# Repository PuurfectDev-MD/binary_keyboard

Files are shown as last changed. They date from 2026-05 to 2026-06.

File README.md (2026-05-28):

# Binary Keyboard
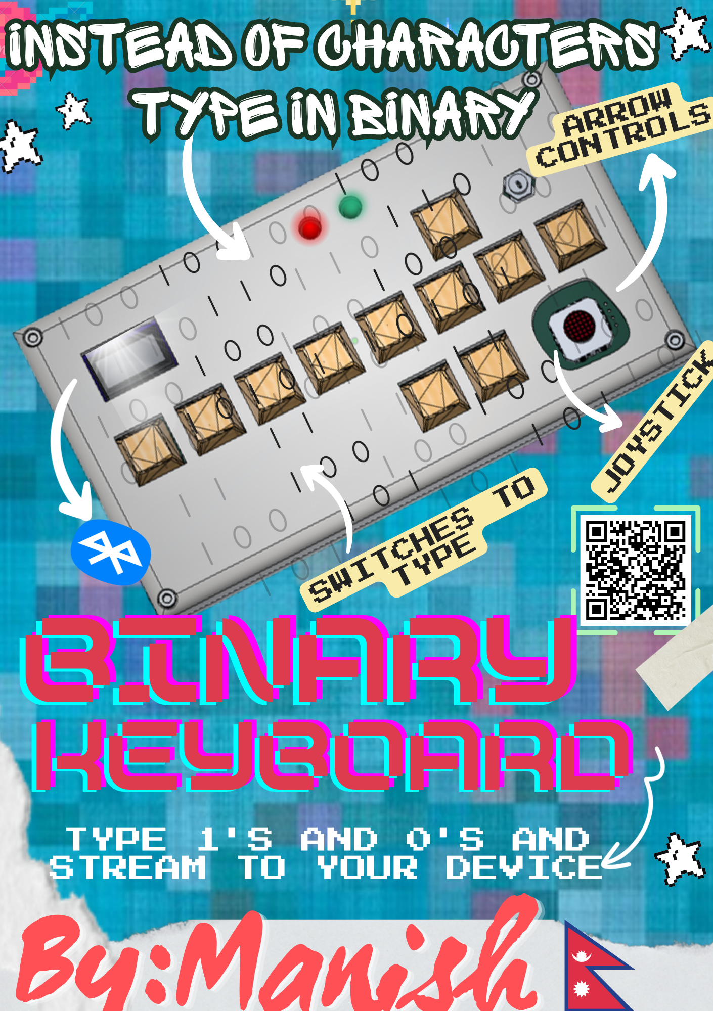
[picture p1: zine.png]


This is wacky, silly project where you can type your keyboard inputs in binary and send it to a connected device. You can enter the byte values (8 switches represent 8 bits in a byte) which represents a character. Then you confirm your input with the enter switch to covert that binary byte to a character to send to your device (wired or wireless!). Basically a keyboard but you type in binary because why not! It uses the SuperMini nRF52840 mcu ( a nice!nano clone) which supports bluetooth connectivity for you to send your inputs wirelessly.

## Motivation
I build the binary keyboard just for the sake of learning. No other motives. Its just a very stupid and fun idea which struck me and there I went building :)

## PCB

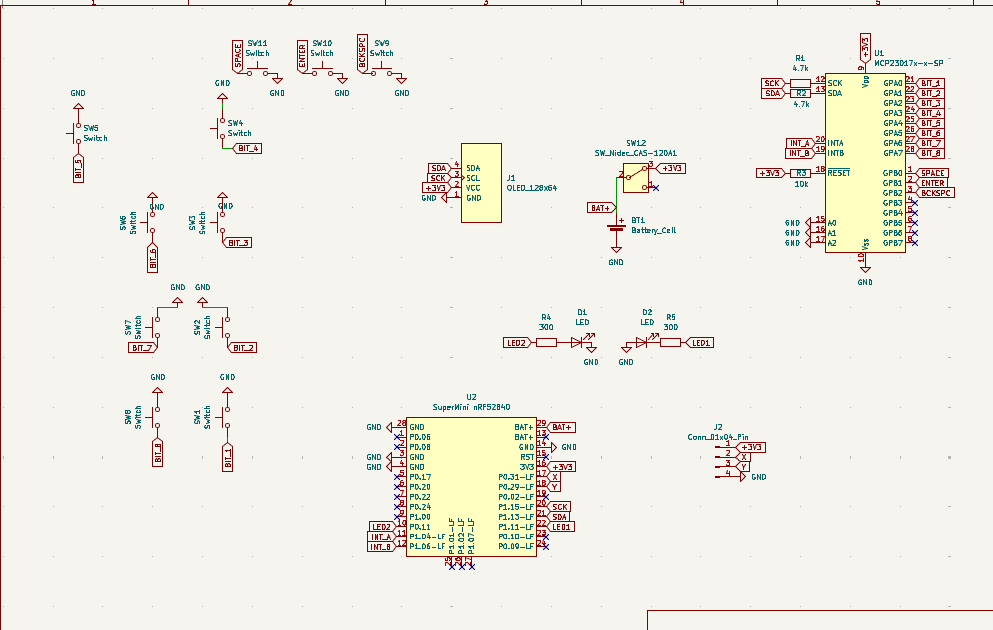
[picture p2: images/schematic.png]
Schematic

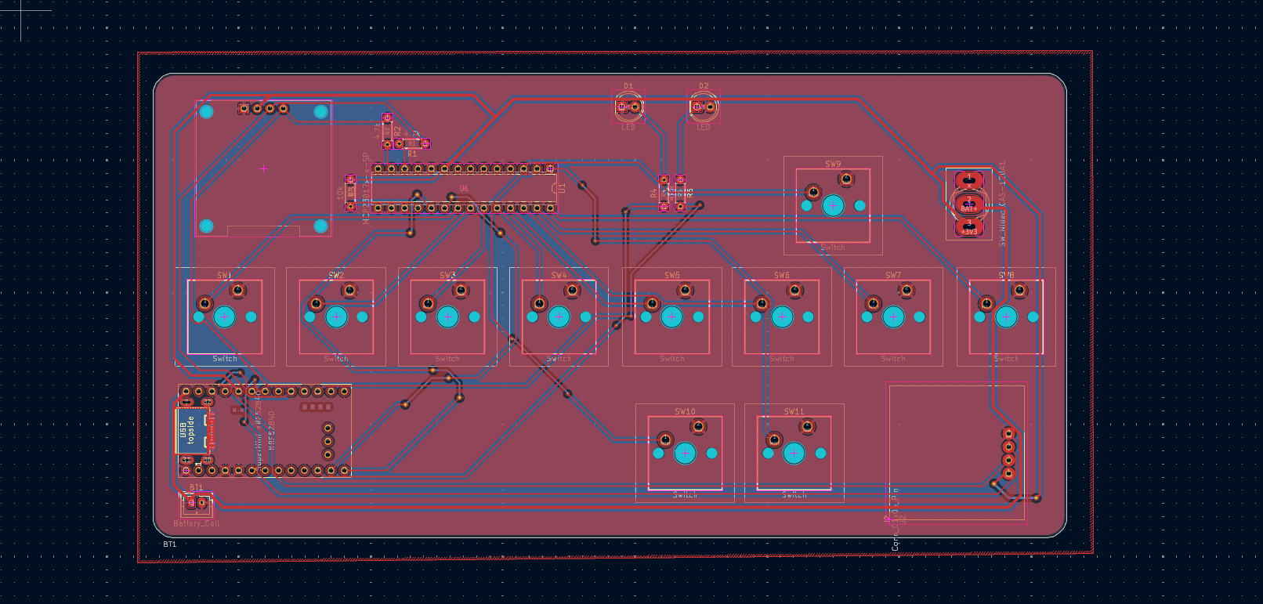
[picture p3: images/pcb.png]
PCB


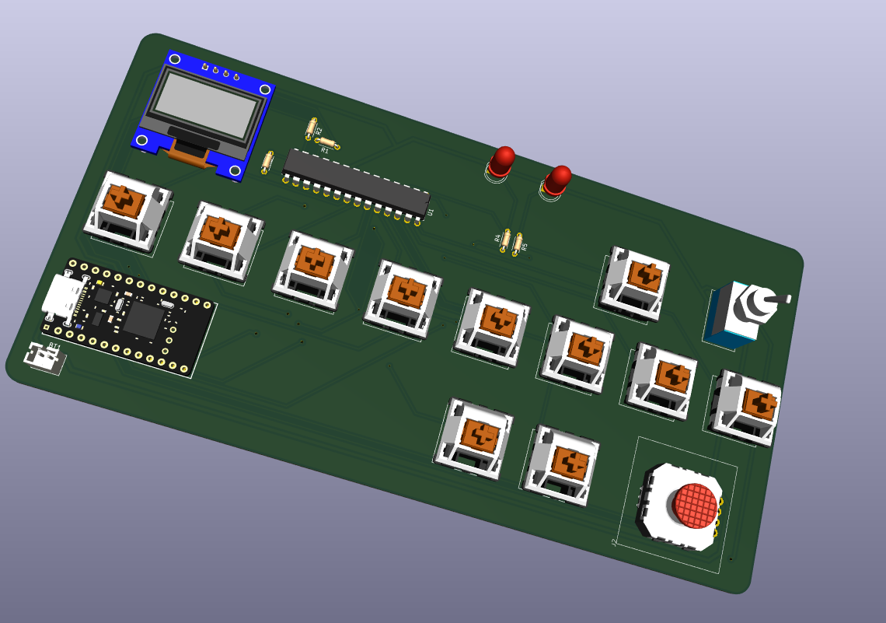
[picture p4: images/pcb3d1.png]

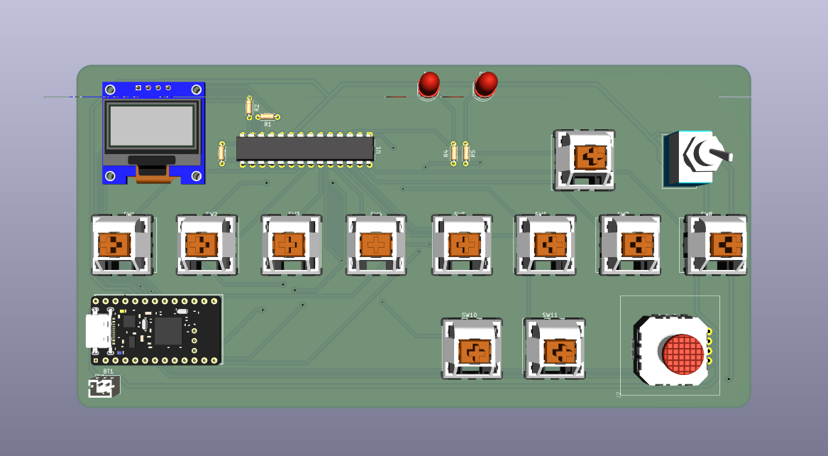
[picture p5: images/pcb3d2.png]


## 3D case
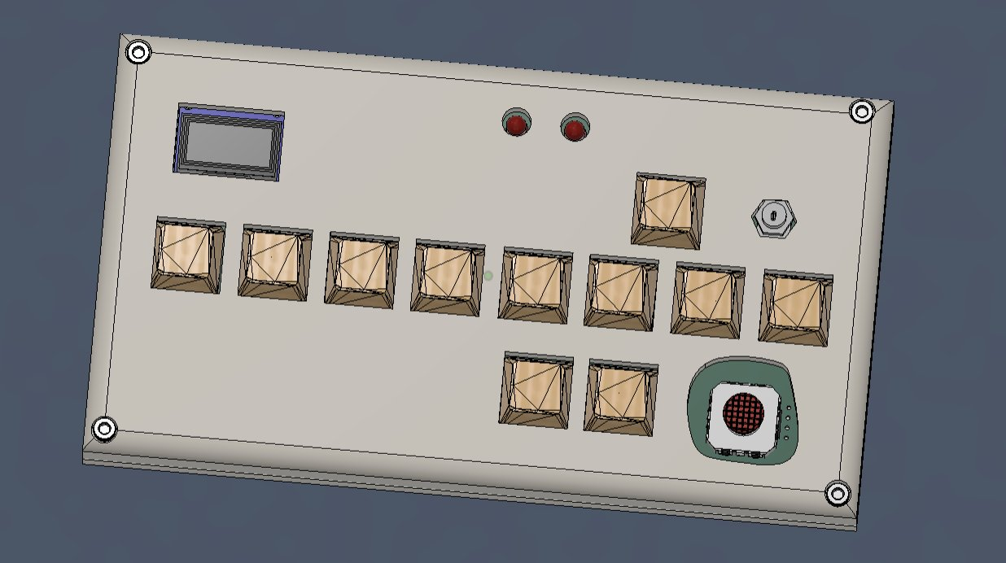
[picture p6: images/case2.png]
Case

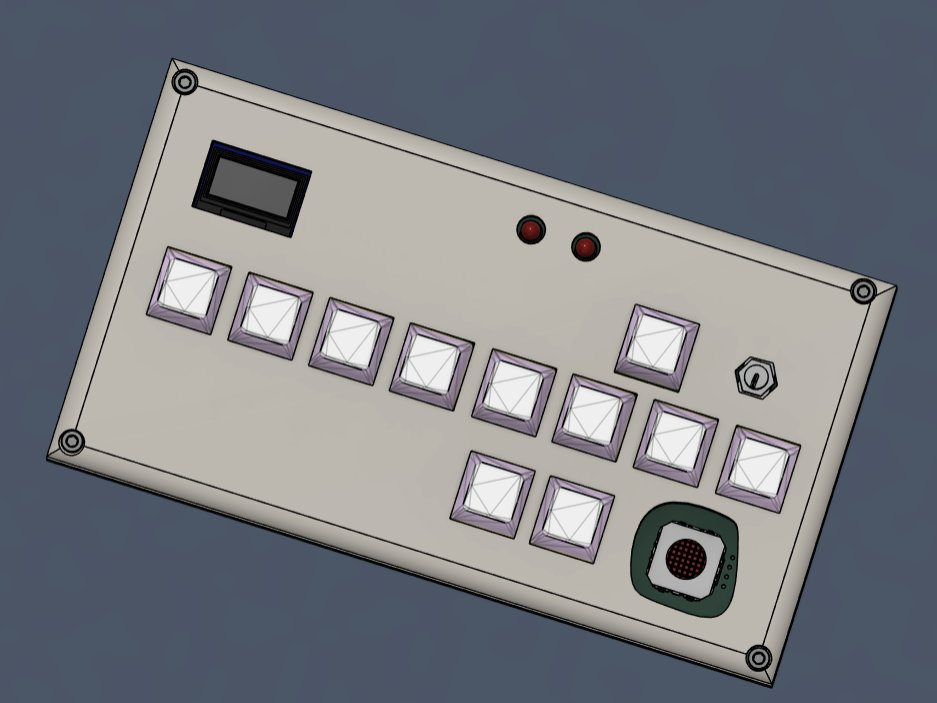
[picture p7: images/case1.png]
Case


##  Project Structure

```text
├── 📁 3d_models
│   ├── 📁 Fusion 360     # Contains the .f3d files and STEP files
│   └── 📁 PCB export     # The 3d file exported from KiCad
├── 📁 KiCad              # Contains the KiCad schematics and PCB files 
├── 📁 Firmware
│   ├── 📁 Circuit Python # Contains the uf2 file that is to be flashed to the supermini
│   ├── 📁 lib            # Contains a zip file for the circuitpython firmware
│   └── 📄 code.py        # Contains the main code
└── 📁 BOM
    ├── 📄 kicad.csv      # KiCad generated CSV (no price present)
    └── 📄 BOM.cBOM mnaully created with price and total estimation
```

## How it works 
There are an array of 8 switches that are connected to the GPA0 to GPA7 of the MCP23017 gpio expander. The GPB0 has three connections - (SPACE, BACKSPACE and ENTER). There are intrerrupts for both of them which are conencted to gpios of the mcu. Whenever a user presses a button (any of the 8 buttons that repsresnt 1 bit of a byte for a single char) the state is changed for that bit's value. So if it was a 0 it changes to 1. Like that we can toggle each of the bits state and at the end press the enter button to confirm the data input. Then the python script (code.py) converted the byte to a char by mapping it to a character and returns it to the USB_HID device for it to be printed on your screen.

## How to make it work for you
First print the PCB. Print the 3d case. Then solder the parts in place. For the firmware- flash the uf2 file in the supermini. Then install the firmware into the mcy by unzippping the file inside /Firmware/lib. And upload the code.py file to begin testing and using the device.    

## AI USE
For firmware guidance and the code.py file code. Teensy help on fusion on selecting screw and other minor stuff. And small help for debugging kicad schematic and suggestions for improvements.

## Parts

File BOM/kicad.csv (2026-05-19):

Reference | Qty | Value | DNP | Exclude from BOM | Exclude from Board | Footprint | Datasheet
BT1 | 1 | Battery_Cell |  |  |  | Connector_JST:JST_PH_B2B-PH-K_1x02_P2.00mm_Vertical
D1,D2 | 2 | LED |  |  |  | LED_THT:LED_D5.0mm
J1 | 1 | OLED_128x64 |  |  |  | ScottoKeebs_Components:OLED_128x64
J2 | 1 | Conn_01x04_Pin |  |  |  | small _yoystick:footprint25.8 * 25.8
R1,R2 | 2 | 4.7k |  |  |  | Resistor_THT:R_Axial_DIN0204_L3.6mm_D1.6mm_P5.08mm_Horizontal
R3 | 1 | 10k |  |  |  | Resistor_THT:R_Axial_DIN0204_L3.6mm_D1.6mm_P5.08mm_Horizontal
R4,R5 | 2 | 300 |  |  |  | Resistor_THT:R_Axial_DIN0204_L3.6mm_D1.6mm_P5.08mm_Horizontal
SW1,SW2,SW3,SW4,SW5,SW6,SW7,SW8,SW9,SW10,SW11 | 11 | Switch |  |  |  | ScottoKeebs_MX:MX_PCB_1.00u
SW12 | 1 | SW_Nidec_CAS-120A1 |  |  |  | Toggle switch:SW_Toggle_Blue_wSlots | https://www.nidec-components.com/e/catalog/switch/cas.pdf
U1 | 1 | MCP23017x-x-SP |  |  |  | Package_DIP:DIP-28_W7.62mm | https://ww1.microchip.com/downloads/aemDocuments/documents/APID/ProductDocuments/DataSheets/MCP23017-Data-Sheet-DS20001952.pdf

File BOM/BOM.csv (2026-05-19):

Name | Quantity | Supplier | Price /$ | Link
Supermini NRF52840 Development Board | 1 | Aliexpress | $5 | https://ar.aliexpress.com/item/1005006035267231.html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"order"%3A"1040"%2C"eval"%3A"1"%2C"sceneId"%3A"30050"%2C"fromPage"%3A"recommend"%7D&pdp_npi=6%40dis%21USD%214.58%214.58%21%21%214.58%214.58%21%40212a6e3217792034453826856e982f%2112000035421753155%21rec%21AE%213090569466%21X%211%210%21n_tag%3A-29919%3Bd%3Aff4fb74f%3Bm03_new_user%3A-29895&utparam-url=scene%3ApcDetailTopMoreOtherSeller%7Cquery_from%3A%7Cx_object_id%3A1005006035267231%7C_p_origin_prod%3A
Dual Axis Joystick | 1 | Aliexpress | $2 | https://ar.aliexpress.com/item/1005004552647663.html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"order"%3A"68"%2C"eval"%3A"1"%2C"sceneId"%3A"30050"%2C"fromPage"%3A"recommend"%7D&pdp_npi=6%40dis%21USD%212.15%212.15%21%21%212.15%212.15%21%40212a6e3217792036300132829e982f%2112000029583802640%21rec%21AE%213090569466%21X%211%210%21n_tag%3A-29919%3Bd%3Aff4fb74f%3Bm03_new_user%3A-29895&utparam-url=scene%3ApcDetailBottomMoreOtherSeller%7Cquery_from%3A%7Cx_object_id%3A1005004552647663%7C_p_origin_prod%3A
Mx Swtiches (Pack of 10) | `1 | Alixpress | $2 | https://ar.aliexpress.com/item/1005012046294210.html?pdp_ext_f=%7B"order"%3A"7"%2C"eval"%3A"1"%2C"fromPage"%3A"search"%7D&pdp_npi=6%40dis%21USD%2112.55%215.52%21%21%2184.87%2137.34%21%402102f0c917792036832868185e9a08%2112000057360279602%21sea%21AE%213090569466%21X%211%210%21n_tag%3A-29919%3Bd%3Aff4fb74f%3Bm03_new_user%3A-29895&curPageLogUid=pdOTt1xmWxan&utparam-url=scene%3Asearch%7Cquery_from%3A%7Cx_object_id%3A1005012046294210%7C_p_origin_prod%3A
Mx Swtiches (Pack of 10) | `1 | Alixpress | $2 | https://ar.aliexpress.com/item/1005012046294210.html?pdp_ext_f=%7B"order"%3A"7"%2C"eval"%3A"1"%2C"fromPage"%3A"search"%7D&pdp_npi=6%40dis%21USD%2112.55%215.52%21%21%2184.87%2137.34%21%402102f0c917792036832868185e9a08%2112000057360279602%21sea%21AE%213090569466%21X%211%210%21n_tag%3A-29919%3Bd%3Aff4fb74f%3Bm03_new_user%3A-29895&curPageLogUid=pdOTt1xmWxan&utparam-url=scene%3Asearch%7Cquery_from%3A%7Cx_object_id%3A1005012046294210%7C_p_origin_prod%3A
MCP23017 GPIO expander | 1 | Aliexpress | $3 | https://ar.aliexpress.com/item/1005009219211233.html?pdp_ext_f=%7B"order"%3A"114"%2C"eval"%3A"1"%2C"fromPage"%3A"search"%7D&pdp_npi=6%40dis%21USD%212.76%212.76%21%21%212.76%212.76%21%40212a70c017792038725917934e6ceb%2112000048356077604%21sea%21AE%213090569466%21X%211%210%21n_tag%3A-29919%3Bd%3Aff4fb74f%3Bm03_new_user%3A-29895&curPageLogUid=HVpjK0uXniRQ&utparam-url=scene%3Asearch%7Cquery_from%3A%7Cx_object_id%3A1005009219211233%7C_p_origin_prod%3A&search_p4p_id=20260519081752152611411338750000129070_6
Chip Socket | 1 | Aliexpress | $1.50 | https://ar.aliexpress.com/item/1005007089348090.html?pdp_ext_f=%7B"order"%3A"149"%2C"eval"%3A"1"%2C"fromPage"%3A"search"%7D&pdp_npi=6%40dis%21USD%210.85%210.85%21%21%215.72%215.72%21%400b1bf20817792039697364292ee5fc%2112000039361104279%21sea%21AE%213090569466%21X%211%210%21n_tag%3A-29919%3Bd%3Aff4fb74f%3Bm03_new_user%3A-29895&curPageLogUid=1FdpneEqxz4B&utparam-url=scene%3Asearch%7Cquery_from%3A%7Cx_object_id%3A1005007089348090%7C_p_origin_prod%3A&search_p4p_id=2026051908192913608418686538480000124685_1
OLED screen 128x64 | 1 | Aliexpress | $4 | https://ar.aliexpress.com/item/1005010757795534.html?pdp_ext_f=%7B"order"%3A"26"%2C"eval"%3A"1"%2C"fromPage"%3A"search"%7D&pdp_npi=6%40dis%21USD%218.34%213.83%21%21%2156.40%2125.94%21%4021010d9017792040590841087e2fce%2112000053411729727%21sea%21AE%213090569466%21X%211%210%21n_tag%3A-29919%3Bd%3Aff4fb74f%3Bm03_new_user%3A-29895&curPageLogUid=hi639f06tMoG&utparam-url=scene%3Asearch%7Cquery_from%3A%7Cx_object_id%3A1005010757795534%7C_p_origin_prod%3A
Toggle switch | 1 | Aliexpress | $2.50 | https://ar.aliexpress.com/item/1005007354903637.html?pdp_ext_f=%7B"order"%3A"42"%2C"eval"%3A"1"%2C"fromPage"%3A"search"%7D&pdp_npi=6%40dis%21USD%212.84%211.70%21%21%2119.22%2111.53%21%40210123bc17792041702397277e2fcf%2112000040398139194%21sea%21AE%213090569466%21X%211%210%21n_tag%3A-29919%3Bd%3Aff4fb74f%3Bm03_new_user%3A-29895&curPageLogUid=vx2Nf84bDKCp&utparam-url=scene%3Asearch%7Cquery_from%3A%7Cx_object_id%3A1005007354903637%7C_p_origin_prod%3A
Lipo battery 2000mah | 1 | Aliexpress | $11 | https://ar.aliexpress.com/item/1005008347608135.html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"order"%3A"700"%2C"spu_best_type"%3A"price"%2C"eval"%3A"1"%2C"sceneId"%3A"30050"%2C"fromPage"%3A"recommend"%7D&pdp_npi=6%40dis%21USD%218.11%215.68%21%21%2154.81%2138.37%21%40212a6e3217792046463128991e982f%2112000044682810370%21rec%21AE%213090569466%21X%211%210%21n_tag%3A-29919%3Bd%3Aff4fb74f%3Bm03_new_user%3A-29895&utparam-url=scene%3ApcDetailTopMoreOtherSeller%7Cquery_from%3A%7Cx_object_id%3A1005008347608135%7C_p_origin_prod%3A
Miselleneous |  |  | $2
 |  |  | Total: 35

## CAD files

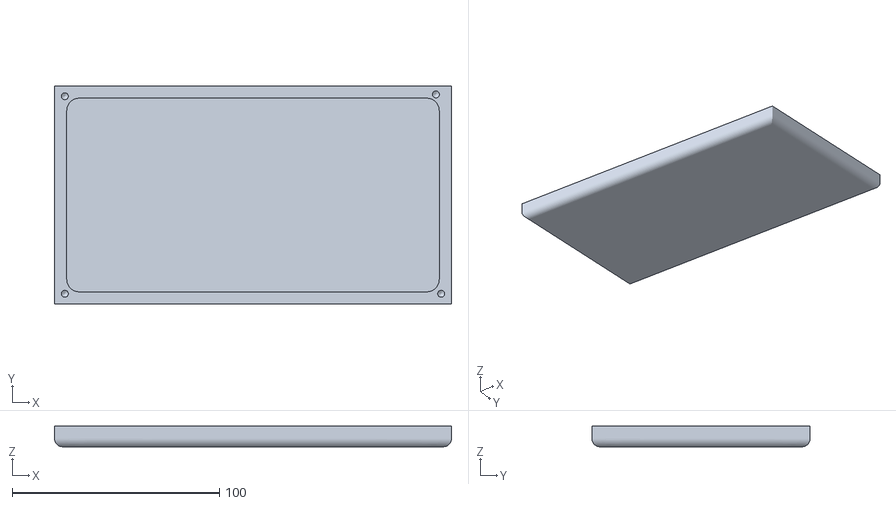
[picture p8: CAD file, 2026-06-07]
3d_models/Fusion 360/STEP files/backplate.stl
191.8 x 105.4 x 10.0

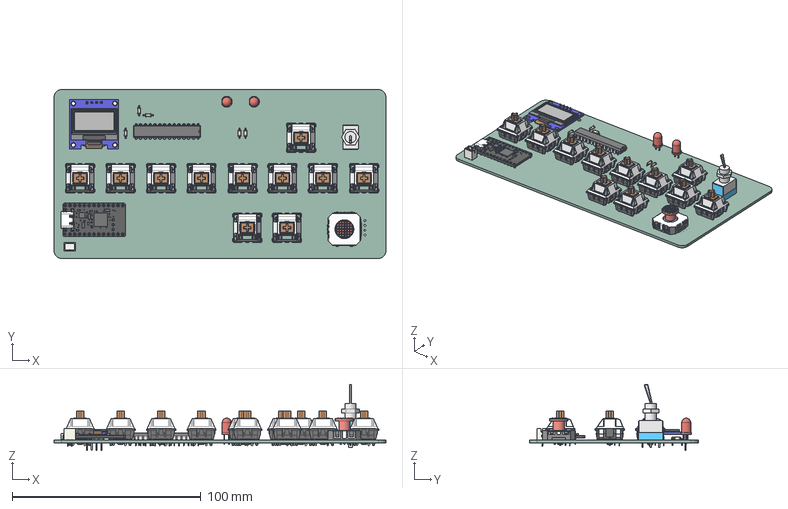
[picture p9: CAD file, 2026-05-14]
3d_models/PCB Export/keyboard.step
175.8 x 89.4 x 35.1 mm
R_Axial_DIN0204_L36mm_D16mm_P508mm_Horizontal x 5
Housing
Chrome
SW_Cherry_MX_PCB_cp x 11
JST_B2B_PH_K
2 Axis Thumbstick v3 v2
LED_D5.0mm x 2
DIP-28_W7.62mm
nice!nano v1.0
mcu-chip-ic-2set-leg v1
LED_0603_1608Metric_ON v1
LED_0603_1608Metric_ON v1(Mirror)
Crystal Oscillator v3
Crystal Oscillator v3 (1)
usb4520-03-0-a v1
C0201 v1 x 28
C0402 v1 x 8
0603 v1 x 2
DM-OLED096-636_Module
DM-OLED096-636_Panel
Binary_keyboard_PCB

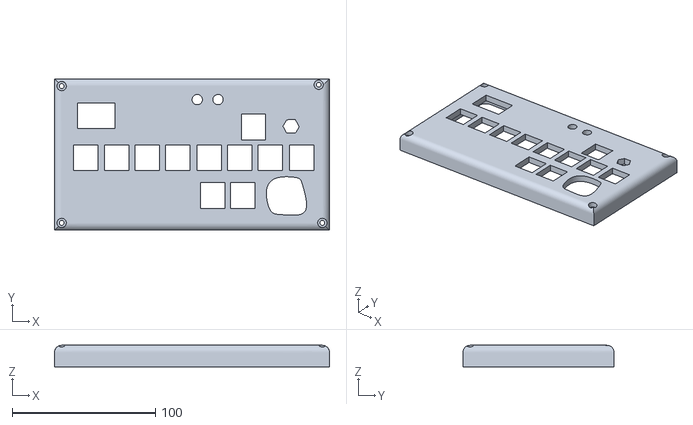
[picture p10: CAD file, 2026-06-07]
3d_models/Fusion 360/STEP files/frontplate.stl
191.8 x 105.4 x 15.0

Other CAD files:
3d_models/Fusion 360/f3d files/assembly.f3d
3d_models/Fusion 360/f3d files/bakplate.f3d
3d_models/Fusion 360/f3d files/frontplate.f3d

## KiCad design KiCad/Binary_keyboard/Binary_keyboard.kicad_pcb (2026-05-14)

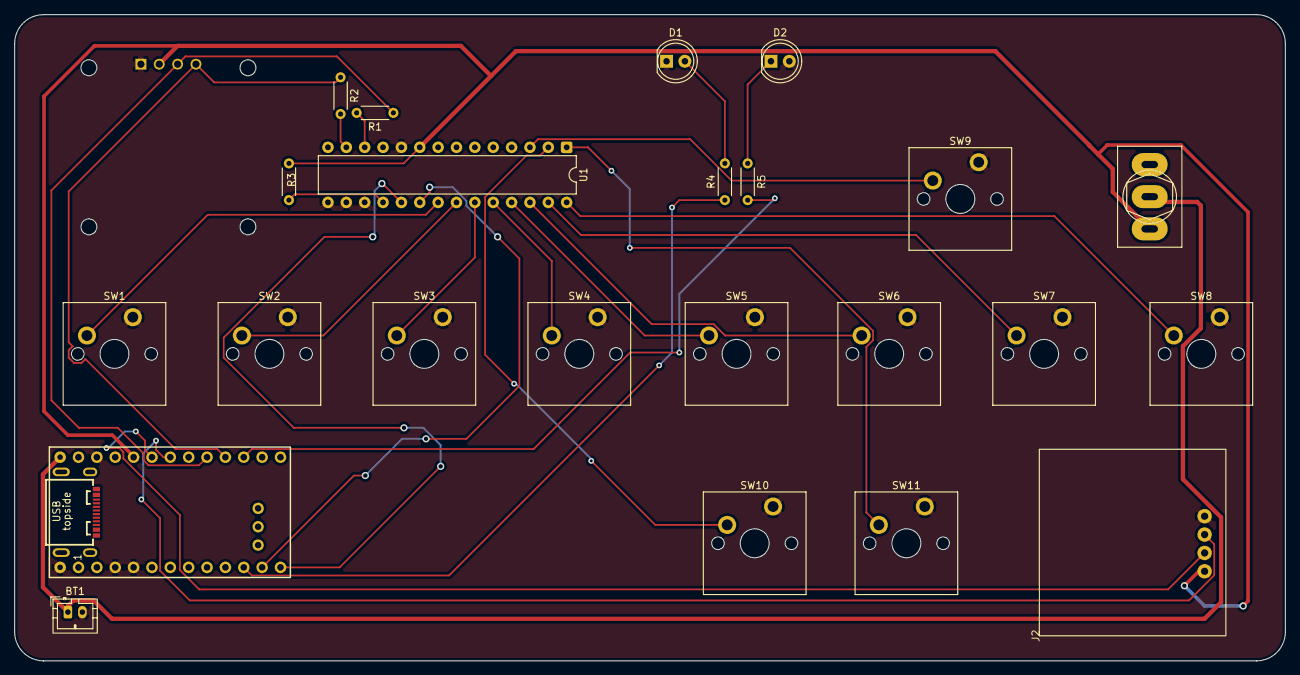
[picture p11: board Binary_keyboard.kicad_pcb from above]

Board: 2 copper layers, 175.8 x 89.4 mm, 24 parts (0 on the bottom side), 27 nets.

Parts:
BT1: Battery_Cell; JST_PH_B2B-PH-K_1x02_P2.00mm_Vertical
D1, D2: LED; LED_D5.0mm
J1: OLED_128x64
J2: Conn_01x04_Pin; footprint25.8 * 25.8
R1, R2: 4.7k; R_Axial_DIN0204_L3.6mm_D1.6mm_P5.08mm_Horizontal
R3: 10k; R_Axial_DIN0204_L3.6mm_D1.6mm_P5.08mm_Horizontal
R4, R5: 300; R_Axial_DIN0204_L3.6mm_D1.6mm_P5.08mm_Horizontal
SW1, SW2, SW3, SW4, SW5, SW6, SW7, SW8, SW9, SW10, SW11: Switch; MX_PCB_1.00u
SW12: SW_Nidec_CAS-120A1; SW_Toggle_Blue_wSlots
U1: MCP23017x-x-SP; DIP-28_W7.62mm
U2: SuperMini nRF52840; SuperMini NRF52840

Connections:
+3V3: J1.2 (VCC), J2.1, R3.1, SW12.3 (A), U1.9 (V_{DD}), U2.16 (3V3)
BAT+: BT1.1 (+), SW12.2 (B), U2.29 (BAT+)
BCKSPC: SW9.1, U1.3 (GPB2)
BIT_1: SW1.1, U1.21 (GPA0)
BIT_2: SW2.1, U1.22 (GPA1)
BIT_3: SW3.1, U1.23 (GPA2)
BIT_4: SW4.1, U1.24 (GPA3)
BIT_5: SW5.1, U1.25 (GPA4)
BIT_6: SW6.1, U1.26 (GPA5)
BIT_7: SW7.1, U1.27 (GPA6)
BIT_8: SW8.1, U1.28 (GPA7)
ENTER: SW10.1, U1.2 (GPB1)
GND: BT1.2 (-), D1.1 (K), D2.2 (A), J1.1 (GND), J2.4, SW1.2, SW2.2, SW3.2, SW4.2, SW5.2, SW6.2, SW7.2, SW8.2, SW9.2, SW10.2, SW11.2, U1.10 (V_{SS}), U1.15 (A0), U1.16 (A1), U1.17 (A2), U2.3 (GND), U2.4 (GND), U2.14 (GND), U2.28 (GND)
INT_A: U1.20 (INTA), U2.11 (P1.04-LF)
INT_B: U1.19 (INTB), U2.12 (P1.06-LF)
LED1: R5.2, U2.22 (P1.11-LF)
LED2: R4.1, U2.10 (P0.11)
unnamed: D1.2 (A), R4.2
unnamed: D2.1 (K), R5.1
unnamed: R1.2, U1.12 (SCK)
unnamed: R2.2, U1.13 (SDA)
unnamed: R3.2, U1.18 (~RESET)
SCK: J1.3 (SCL), R1.1, U2.20 (P1.15-LF)
SDA: J1.4 (SDA), R2.1, U2.21 (P1.13-LF)
SPACE: SW11.1, U1.1 (GPB0)
X: J2.2, U2.17 (P0.31-LF)
Y: J2.3, U2.18 (P0.29-LF)

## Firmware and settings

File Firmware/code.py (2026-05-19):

import board
import busio
import usb_hid
import time
import displayio
import terminalio
from adafruit_display_text import label
import adafruit_ssd1306
from adafruit_mcp230xx.mcp23017 import MCP23017
from digitalio import Direction, Pull
from adafruit_hid.keyboard import Keyboard
from adafruit_hid.keycode import Keycode

# ── I2C bus (shared by MCP23017 + SSD1306) ───────────────────────────
i2c = busio.I2C(scl=board.P1_15, sda=board.P1_13)

# ── OLED SSD1306 128x64 (default I2C address 0x3C) ───────────────────
oled = adafruit_ssd1306.SSD1306_I2C(128, 64, i2c, addr=0x3C)

def oled_clear():
    oled.fill(0)

def oled_show(title, bits, value, char_preview, sent_history):
    """Render the full display layout."""
    oled.fill(0)

    # Row 0: static title (y=0)
    oled.text("BINARY KEYBOARD", 0, 0, 1)

    # Row 1: horizontal line separator (y=9)
    oled.hline(0, 9, 128, 1)

    # Row 2: bit pattern + decimal (y=13)
    bit_str = f"{value:08b}"           # e.g. "01000001"
    oled.text(f"{bit_str} ({value})", 0, 13, 1)

    # Row 3: mapped character preview (y=27)
    if char_preview:
        oled.text(f"-> '{char_preview}'", 0, 27, 1)
    else:
        oled.text("-> (no mapping)", 0, 27, 1)

    # Row 4: horizontal line separator (y=40)
    oled.hline(0, 40, 128, 1)

    # Row 5: last sent characters (y=44)
    history_str = "".join(sent_history[-14:])   # fit ~14 chars on width
    oled.text(f"Sent:{history_str}", 0, 44, 1)

    # Row 6: button hint (y=55)
    oled.text("B0=SND B1=ENT", 0, 55, 1)

    oled.show()


# ── MCP23017 (address 0x20, set by A0/A1/A2 all to GND) ──────────────
mcp = MCP23017(i2c, address=0x20)

# ── Port A: 8 binary toggle switches (GPA0–GPA7) ─────────────────────
switches = []
for pin_num in range(8):
    pin = mcp.get_pin(pin_num)
    pin.direction = Direction.INPUT
    pin.pull = Pull.UP
    switches.append(pin)

# ── Port B: action buttons (GPB0–GPB3 = MCP pins 8–11) ───────────────
BTN_SEND      = mcp.get_pin(8)     # GPB0 — send binary byte
BTN_ENTER     = mcp.get_pin(9)     # GPB1 — enter
BTN_BACKSPACE = mcp.get_pin(10)    # GPB2 — backspace
BTN_SPACE     = mcp.get_pin(11)    # GPB3 — space

for btn in [BTN_SEND, BTN_ENTER, BTN_BACKSPACE, BTN_SPACE]:
    btn.direction = Direction.INPUT
    btn.pull = Pull.UP

# ── USB HID Keyboard ──────────────────────────────────────────────────
kbd = Keyboard(usb_hid.devices)

# ── Sent history (rolling buffer of last 14 chars) ────────────────────
sent_history = []

# ── Character mapping ─────────────────────────────────────────────────
def char_to_keycode(char):
    if 'a' <= char <= 'z':
        return getattr(Keycode, char.upper()), False
    if 'A' <= char <= 'Z':
        return getattr(Keycode, char), True

    digit_map = {
        '0': (Keycode.ZERO, False),  '1': (Keycode.ONE, False),
        '2': (Keycode.TWO, False),   '3': (Keycode.THREE, False),
        '4': (Keycode.FOUR, False),  '5': (Keycode.FIVE, False),
        '6': (Keycode.SIX, False),   '7': (Keycode.SEVEN, False),
        '8': (Keycode.EIGHT, False), '9': (Keycode.NINE, False),
    }
    if char in digit_map:
        return digit_map[char]

    symbol_map = {
        ' ': (Keycode.SPACE, False),
        '\n': (Keycode.ENTER, False),
        '.': (Keycode.PERIOD, False),        ',': (Keycode.COMMA, False),
        '!': (Keycode.ONE, True),            '@': (Keycode.TWO, True),
        '#': (Keycode.THREE, True),          '$': (Keycode.FOUR, True),
        '%': (Keycode.FIVE, True),           '^': (Keycode.SIX, True),
        '&': (Keycode.SEVEN, True),          '*': (Keycode.EIGHT, True),
        '(': (Keycode.NINE, True),           ')': (Keycode.ZERO, True),
        '-': (Keycode.MINUS, False),         '_': (Keycode.MINUS, True),
        '=': (Keycode.EQUALS, False),        '+': (Keycode.EQUALS, True),
        '[': (Keycode.LEFT_BRACKET, False),  ']': (Keycode.RIGHT_BRACKET, False),
        '{': (Keycode.LEFT_BRACKET, True),   '}': (Keycode.RIGHT_BRACKET, True),
        ';': (Keycode.SEMICOLON, False),     ':': (Keycode.SEMICOLON, True),
        "'": (Keycode.QUOTE, False),         '"': (Keycode.QUOTE, True),
        '/': (Keycode.FORWARD_SLASH, False), '?': (Keycode.FORWARD_SLASH, True),
        '\\': (Keycode.BACKSLASH, False),    '|': (Keycode.BACKSLASH, True),
        '`': (Keycode.GRAVE_ACCENT, False),  '~': (Keycode.GRAVE_ACCENT, True),
        '<': (Keycode.COMMA, True),          '>': (Keycode.PERIOD, True),
    }
    return symbol_map.get(char, (None, False))


def byte_to_keycode(value):
    if 32 <= value <= 126:
        return char_to_keycode(chr(value))
    return None, False


def read_byte():
    value = 0
    for bit, switch in enumerate(switches):
        if not switch.value:
            value |= (1 << bit)
    return value


def send_key(keycode, shift=False):
    if shift:
        kbd.press(Keycode.LEFT_SHIFT, keycode)
    else:
        kbd.press(keycode)
    kbd.release_all()


def get_char_preview(value):
    """Return printable char string or None."""
    if 32 <= value <= 126:
        return chr(value)
    return None


# ── Startup splash ────────────────────────────────────────────────────
oled.fill(0)
oled.text("BINARY KEYBOARD", 10, 20, 1)
oled.text("   initializing...", 0, 36, 1)
oled.show()
time.sleep(1.5)

# ── Button state tracking ─────────────────────────────────────────────
last_send      = True
last_enter     = True
last_backspace = True
last_space     = True
last_byte      = -1         # track toggle changes for live OLED refresh

print("Binary keyboard ready.")

# ── Initial display render ────────────────────────────────────────────
current_byte = read_byte()
oled_show("BINARY KEYBOARD", f"{current_byte:08b}", current_byte,
          get_char_preview(current_byte), sent_history)

# ── Main loop ─────────────────────────────────────────────────────────
while True:
    s_send      = BTN_SEND.value
    s_enter     = BTN_ENTER.value
    s_backspace = BTN_BACKSPACE.value
    s_space     = BTN_SPACE.value

    current_byte = read_byte()

    # Refresh OLED only when toggle state changes (avoid constant redraw)
    if current_byte != last_byte:
        oled_show("BINARY KEYBOARD", f"{current_byte:08b}", current_byte,
                  get_char_preview(current_byte), sent_history)
        last_byte = current_byte

    # SEND — map byte → keycode → send
    if last_send and not s_send:
        char = get_char_preview(current_byte)
        print(f"SEND → {current_byte:08b} ({current_byte}) = '{char}'")
        keycode, needs_shift = byte_to_keycode(current_byte)
        if keycode is not None:
            send_key(keycode, needs_shift)
            sent_history.append(char)
        else:
            sent_history.append("?")
        # Keep history buffer trimmed
        if len(sent_history) > 14:
            sent_history.pop(0)
        oled_show("BINARY KEYBOARD", f"{current_byte:08b}", current_byte,
                  char, sent_history)
        time.sleep(0.05)

    # ENTER
    if last_enter and not s_enter:
        print("ENTER")
        send_key(Keycode.ENTER)
        sent_history.append("↵")
        if len(sent_history) > 14:
            sent_history.pop(0)
        oled_show("BINARY KEYBOARD", f"{current_byte:08b}", current_byte,
                  get_char_preview(current_byte), sent_history)
        time.sleep(0.05)

    # BACKSPACE
    if last_backspace and not s_backspace:
        print("BACKSPACE")
        send_key(Keycode.BACKSPACE)
        if sent_history:
            sent_history.pop()          # remove last sent char
        oled_show("BINARY KEYBOARD", f"{current_byte:08b}", current_byte,
                  get_char_preview(current_byte), sent_history)
        time.sleep(0.05)

    # SPACE
    if last_space and not s_space:
        print("SPACE")
        send_key(Keycode.SPACE)
        sent_history.append("_")        # visual space indicator
        if len(sent_history) > 14:
            sent_history.pop(0)
        oled_show("BINARY KEYBOARD", f"{current_byte:08b}", current_byte,
                  get_char_preview(current_byte), sent_history)
        time.sleep(0.05)

    last_send      = s_send
    last_enter     = s_enter
    last_backspace = s_backspace
    last_space     = s_space

    time.sleep(0.01)

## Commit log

2026-05-12 First commit - schematic setup
    [Binary_keyboard.kicad_pcb, Binary_keyboard.kicad_sch]
2026-05-14 Case and zine
    [Binary_keyboard.kicad_pcb, bakplate.f3d, frontplate.f3d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]
2026-05-19 Added firmware, BOM and README.md update
    [BOM.csv, kicad.csv]
2026-06-07 Added assembly file and removed backup files
    [assembly.f3d]
2026-06-07 STL files
    [backplate.stl, frontplate.stl]
